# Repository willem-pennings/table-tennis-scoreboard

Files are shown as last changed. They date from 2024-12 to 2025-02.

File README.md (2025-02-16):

# Table tennis scoreboard
Hardware and software design for an electronic table tennis score board.

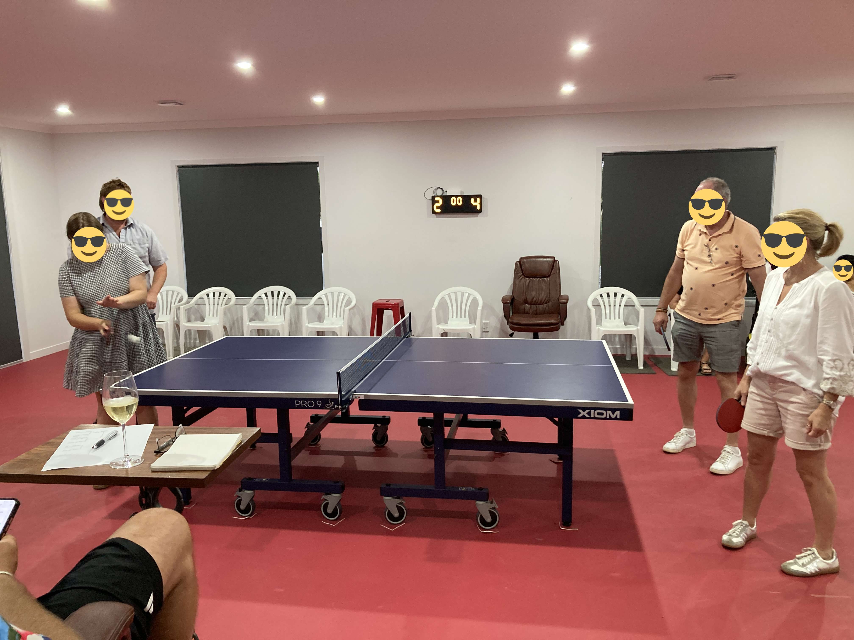
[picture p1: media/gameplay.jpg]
table tennis gameplay using the electronic scoreboard


## Features
This device has the following characteristics:
- Keeps track of scores, number of games, and timeouts.
- Remotely controlled using Wi-Fi and a web server.
- A mechanical design which is mainly based on laser-cut parts.
- WS2813 LEDs: adjustable screen colour and brightness.
- Software runs on an ESP32-S3.

## Building it
Mechanical parts are laser-cut from sheet material. An overview of individual parts:
- [Perspex Frost Midnight Black 9221, 3 mm thickness](https://www.laserbeest.nl/materialen/acrylaat-zwart-frost-3mm/)
  - ``front.svg``
  - ``back.svg``
  - ``wall-side-no-holes.svg``
  - ``wall-side-with-holes.svg``
  - ``wall-top-bottom.svg``
- [Perspex Frost Slate Grey 9T23, 3 mm thickness](https://www.laserbeest.nl/materialen/acrylaat-frost-donkergrijs-3-mm/)
  - ``diffuser-major.svg``
  - ``diffuser-minor.svg``
  - ``diffuser-timeout.svg``
- [PE rigid foam, 20 mm thickness](https://snijlab.nl/en/products/pe-rigid-foam?variant=48708138500423)
  - ``lightbox.svg``

Production files have also been prepared which can be sent to Dutch lasercutting companies as-is:
 - ``mechanical/production/production-laserbeest.pdf``
 - ``mechanical/production/production-snijlab.pdf``

The following additional parts are required to assemble the enclosure:
- 50x ISO7380 screw, M3x10.
- 15x M3x50 standoff, fully threaded, black ([example](https://www.aliexpress.com/item/1005004063804402.html)).
- 15x M3x20 standoff, fully threaded ([example](https://www.aliexpress.com/item/4000152799825.html)).
- USB type C extension cable ([example](https://www.aliexpress.com/item/1005005446667716.html)).
- Cyanoacrylate glue to join the frosted diffusers to the front plate.

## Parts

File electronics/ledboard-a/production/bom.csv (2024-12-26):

Designator | Footprint | Quantity | Value | LCSC Part #
C1, C10, C11, C12, C13, C14, C15, C16, C17, C18, C19, C2, C20, C21, C22, C23, C24, C25, C26, C27, C28, C29, C3, C30, C31, C32, C33, C34, C35, C36, C37, C38, C39, C4, C40, C41, C42, C43, C44, C45, C46, C47, C48, C49, C5, C50, C51, C52, C53, C54, C55, C56, C57, C58, C59, C6, C60, C61, C62, C63, C64, C65, C66, C67, C68, C69, C7, C70, C71, C72, C73, C74, C75, C8, C9 | 0603 | 75 | 100 nF | C14663
D1, D10, D11, D12, D13, D14, D15, D16, D17, D18, D19, D2, D20, D21, D22, D23, D24, D25, D26, D27, D28, D29, D3, D30, D31, D32, D33, D34, D35, D36, D37, D38, D39, D4, D40, D41, D42, D43, D44, D45, D46, D47, D48, D49, D5, D50, D51, D52, D53, D54, D55, D56, D57, D58, D59, D6, D60, D61, D62, D63, D64, D65, D66, D67, D68, D69, D7, D70, D71, D72, D73, D74, D75, D8, D9 | LED_WS2812_PLCC6_5.0x5.0mm_P1.6mm | 75 | WS2813 | C160214
H1, H2, H3, H4, H5 | MountingHole_3.2mm_M3_DIN965_Pad | 5 | MountingHole
J1 | Dorabo DB128V-5.08-2P | 1 | Conn_01x02
J2 | Dorabo DB128V-5.08-4P | 1 | Conn_01x04
KiKit_FID_B_1, KiKit_FID_B_2, KiKit_FID_B_3, KiKit_FID_B_4, KiKit_FID_T_1, KiKit_FID_T_2, KiKit_FID_T_3, KiKit_FID_T_4 | Fiducial | 8 | Fiducial
KiKit_MB_1_1, KiKit_MB_1_2, KiKit_MB_1_3, KiKit_MB_1_4, KiKit_MB_1_5, KiKit_MB_1_6, KiKit_MB_1_7, KiKit_MB_1_8, KiKit_MB_2_1, KiKit_MB_2_2, KiKit_MB_2_3, KiKit_MB_2_4, KiKit_MB_2_5, KiKit_MB_2_6, KiKit_MB_2_7, KiKit_MB_2_8, KiKit_MB_3_1, KiKit_MB_3_2, KiKit_MB_3_3, KiKit_MB_3_4, KiKit_MB_3_5, KiKit_MB_3_6, KiKit_MB_3_7, KiKit_MB_3_8, KiKit_MB_4_1, KiKit_MB_4_2, KiKit_MB_4_3, KiKit_MB_4_4, KiKit_MB_4_5, KiKit_MB_4_6, KiKit_MB_4_7, KiKit_MB_4_8, KiKit_MB_5_1, KiKit_MB_5_2, KiKit_MB_5_3, KiKit_MB_5_4, KiKit_MB_5_5, KiKit_MB_5_6, KiKit_MB_5_7, KiKit_MB_5_8, KiKit_MB_6_1, KiKit_MB_6_2, KiKit_MB_6_3, KiKit_MB_6_4, KiKit_MB_6_5, KiKit_MB_6_6, KiKit_MB_6_7, KiKit_MB_6_8, KiKit_MB_7_1, KiKit_MB_7_2, KiKit_MB_7_3, KiKit_MB_7_4, KiKit_MB_7_5, KiKit_MB_7_6, KiKit_MB_7_7, KiKit_MB_7_8, KiKit_MB_8_1, KiKit_MB_8_2, KiKit_MB_8_3, KiKit_MB_8_4, KiKit_MB_8_5, KiKit_MB_8_6, KiKit_MB_8_7, KiKit_MB_8_8, KiKit_TO_1, KiKit_TO_2, KiKit_TO_3 | NPTH | 67 | NPTH
TH1, TH2, TH3 | JLCPCB tooling hole | 3 | MountingHole

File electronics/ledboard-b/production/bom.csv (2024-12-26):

Designator | Footprint | Quantity | Value | LCSC Part #
C100, C101, C102, C103, C104, C105, C106, C107, C108, C109, C110, C111, C112, C113, C114, C115, C116, C117, C118, C119, C120, C121, C122, C123, C124, C125, C126, C127, C128, C129, C130, C131, C132, C133, C134, C135, C136, C137, C138, C139, C140, C141, C142, C143, C144, C145, C146, C147, C148, C149, C150, C76, C77, C78, C79, C80, C81, C82, C83, C84, C85, C86, C87, C88, C89, C90, C91, C92, C93, C94, C95, C96, C97, C98, C99 | 0603 | 75 | 100 nF | C14663
D100, D101, D102, D103, D104, D105, D106, D107, D108, D109, D110, D111, D112, D113, D114, D115, D116, D117, D118, D119, D120, D121, D122, D123, D124, D125, D126, D127, D128, D129, D130, D131, D132, D133, D134, D135, D136, D137, D138, D139, D140, D141, D142, D143, D144, D145, D146, D147, D148, D149, D150, D76, D77, D78, D79, D80, D81, D82, D83, D84, D85, D86, D87, D88, D89, D90, D91, D92, D93, D94, D95, D96, D97, D98, D99 | LED_WS2812_PLCC6_5.0x5.0mm_P1.6mm | 75 | WS2813 | C160214
H1, H2, H3, H4, H5 | MountingHole_3.2mm_M3_DIN965_Pad | 5 | MountingHole
J1 | Dorabo DB128V-5.08-4P | 1 | Conn_01x04
J2 | Dorabo DB128V-5.08-2P | 1 | Conn_01x02
KiKit_FID_B_1, KiKit_FID_B_2, KiKit_FID_B_3, KiKit_FID_B_4, KiKit_FID_T_1, KiKit_FID_T_2, KiKit_FID_T_3, KiKit_FID_T_4 | Fiducial | 8 | Fiducial
KiKit_MB_1_1, KiKit_MB_1_2, KiKit_MB_1_3, KiKit_MB_1_4, KiKit_MB_1_5, KiKit_MB_1_6, KiKit_MB_1_7, KiKit_MB_1_8, KiKit_MB_2_1, KiKit_MB_2_2, KiKit_MB_2_3, KiKit_MB_2_4, KiKit_MB_2_5, KiKit_MB_2_6, KiKit_MB_2_7, KiKit_MB_2_8, KiKit_MB_3_1, KiKit_MB_3_2, KiKit_MB_3_3, KiKit_MB_3_4, KiKit_MB_3_5, KiKit_MB_3_6, KiKit_MB_3_7, KiKit_MB_3_8, KiKit_MB_4_1, KiKit_MB_4_2, KiKit_MB_4_3, KiKit_MB_4_4, KiKit_MB_4_5, KiKit_MB_4_6, KiKit_MB_4_7, KiKit_MB_4_8, KiKit_MB_5_1, KiKit_MB_5_2, KiKit_MB_5_3, KiKit_MB_5_4, KiKit_MB_5_5, KiKit_MB_5_6, KiKit_MB_5_7, KiKit_MB_5_8, KiKit_MB_6_1, KiKit_MB_6_2, KiKit_MB_6_3, KiKit_MB_6_4, KiKit_MB_6_5, KiKit_MB_6_6, KiKit_MB_6_7, KiKit_MB_6_8, KiKit_MB_7_1, KiKit_MB_7_2, KiKit_MB_7_3, KiKit_MB_7_4, KiKit_MB_7_5, KiKit_MB_7_6, KiKit_MB_7_7, KiKit_MB_7_8, KiKit_MB_8_1, KiKit_MB_8_2, KiKit_MB_8_3, KiKit_MB_8_4, KiKit_MB_8_5, KiKit_MB_8_6, KiKit_MB_8_7, KiKit_MB_8_8, KiKit_TO_1, KiKit_TO_2, KiKit_TO_3 | NPTH | 67 | NPTH
TH1, TH2, TH3 | JLCPCB tooling hole | 3 | MountingHole

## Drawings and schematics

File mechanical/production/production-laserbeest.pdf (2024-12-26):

## PLAAT#: 03 PLAAT#: 02

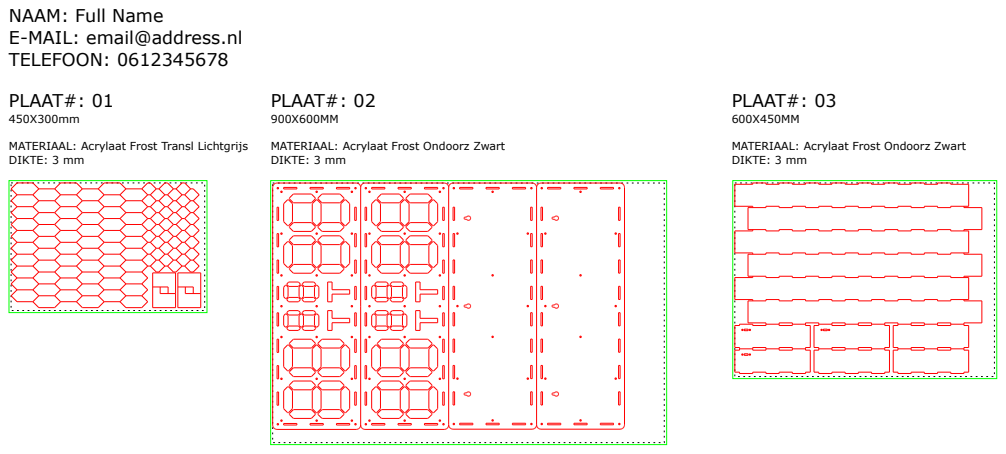
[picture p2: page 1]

NAAM: Full Name
E-MAIL: email@address.nl
TELEFOON: 0612345678
PLAAT#: 01

MATERIAAL: Acrylaat Frost Transl Lichtgrijs
DIKTE: 3 mm

MATERIAAL: Acrylaat Frost Ondoorz Zwart

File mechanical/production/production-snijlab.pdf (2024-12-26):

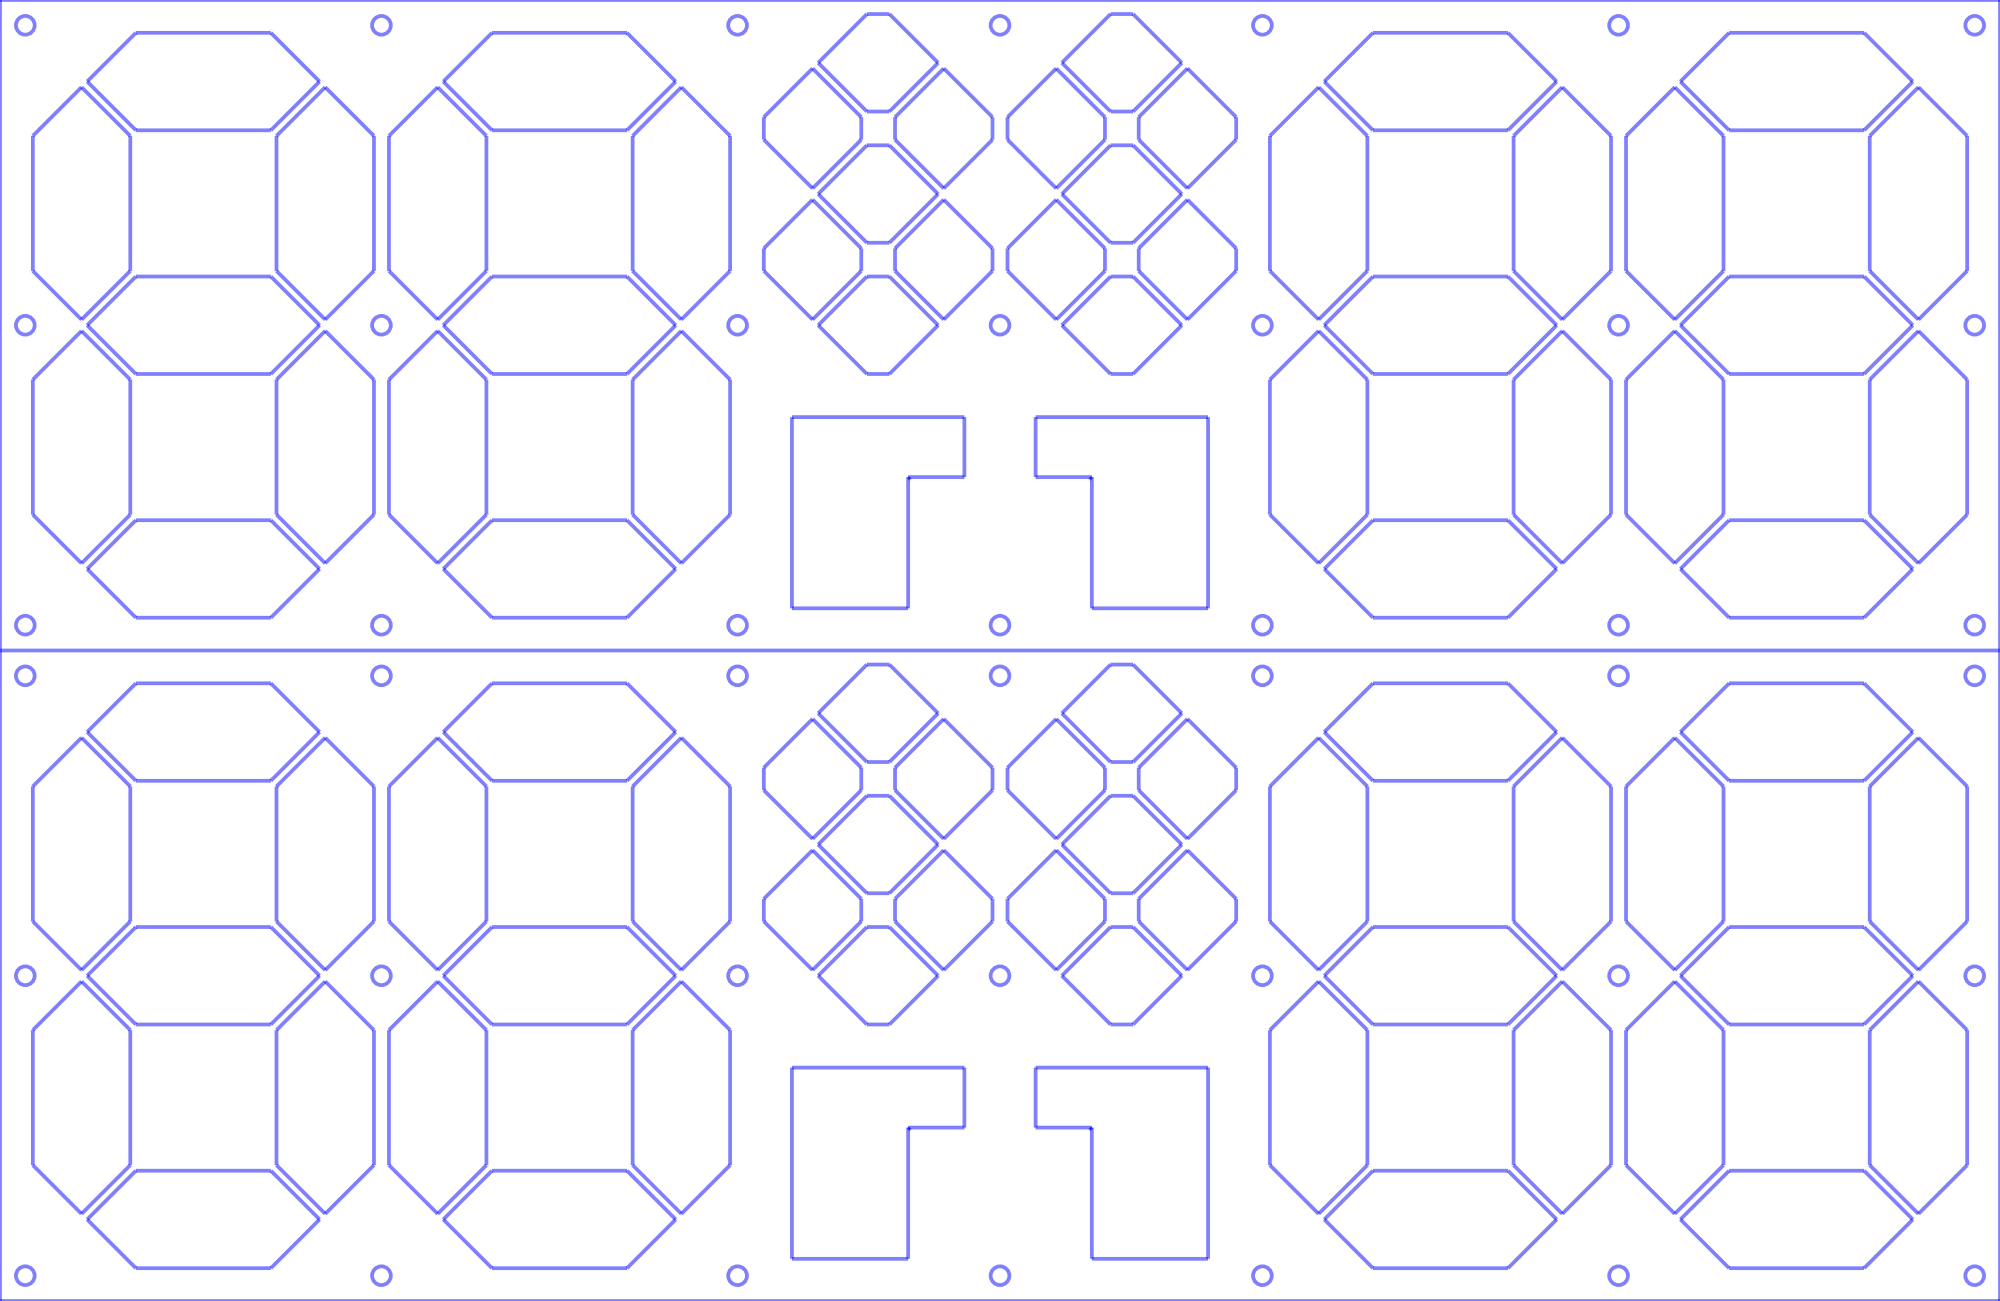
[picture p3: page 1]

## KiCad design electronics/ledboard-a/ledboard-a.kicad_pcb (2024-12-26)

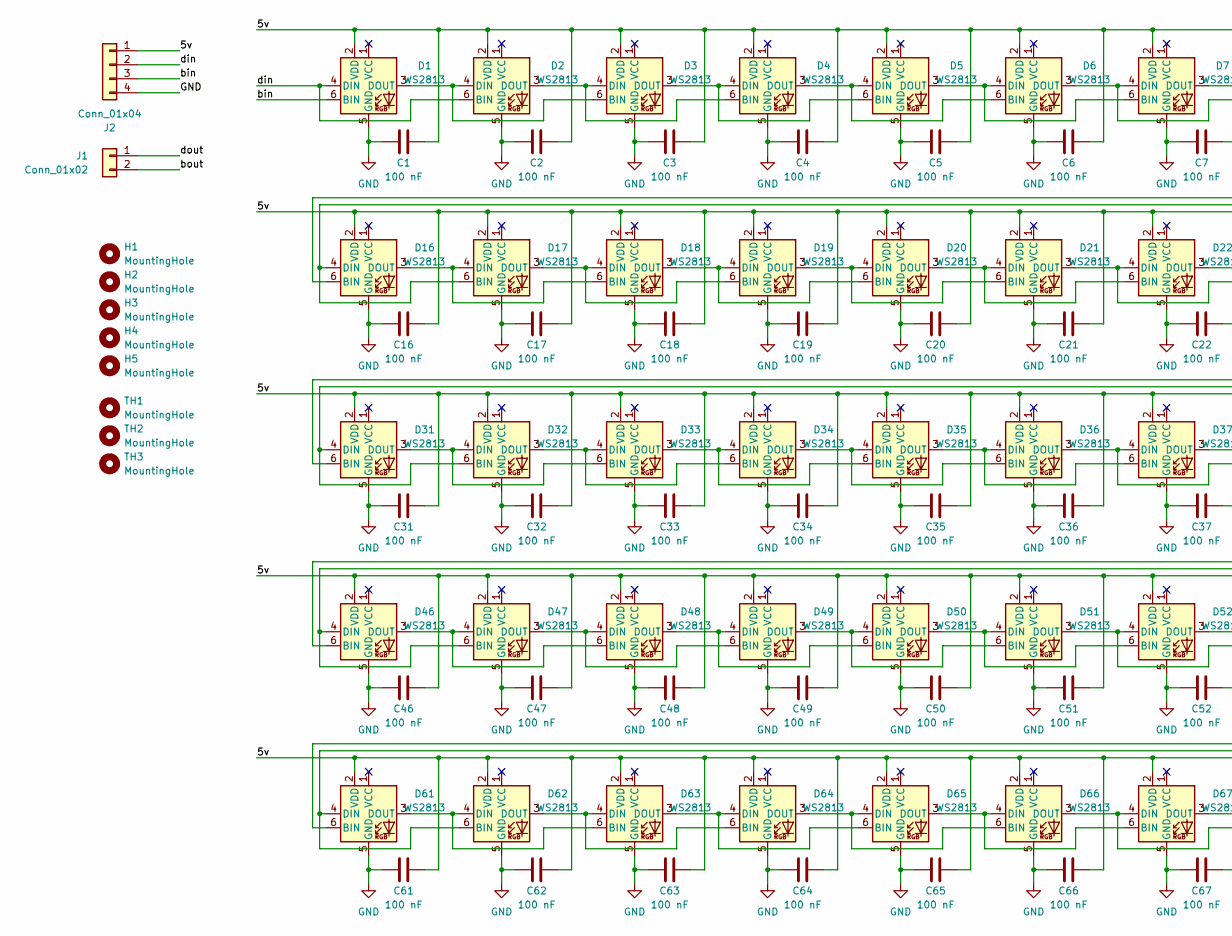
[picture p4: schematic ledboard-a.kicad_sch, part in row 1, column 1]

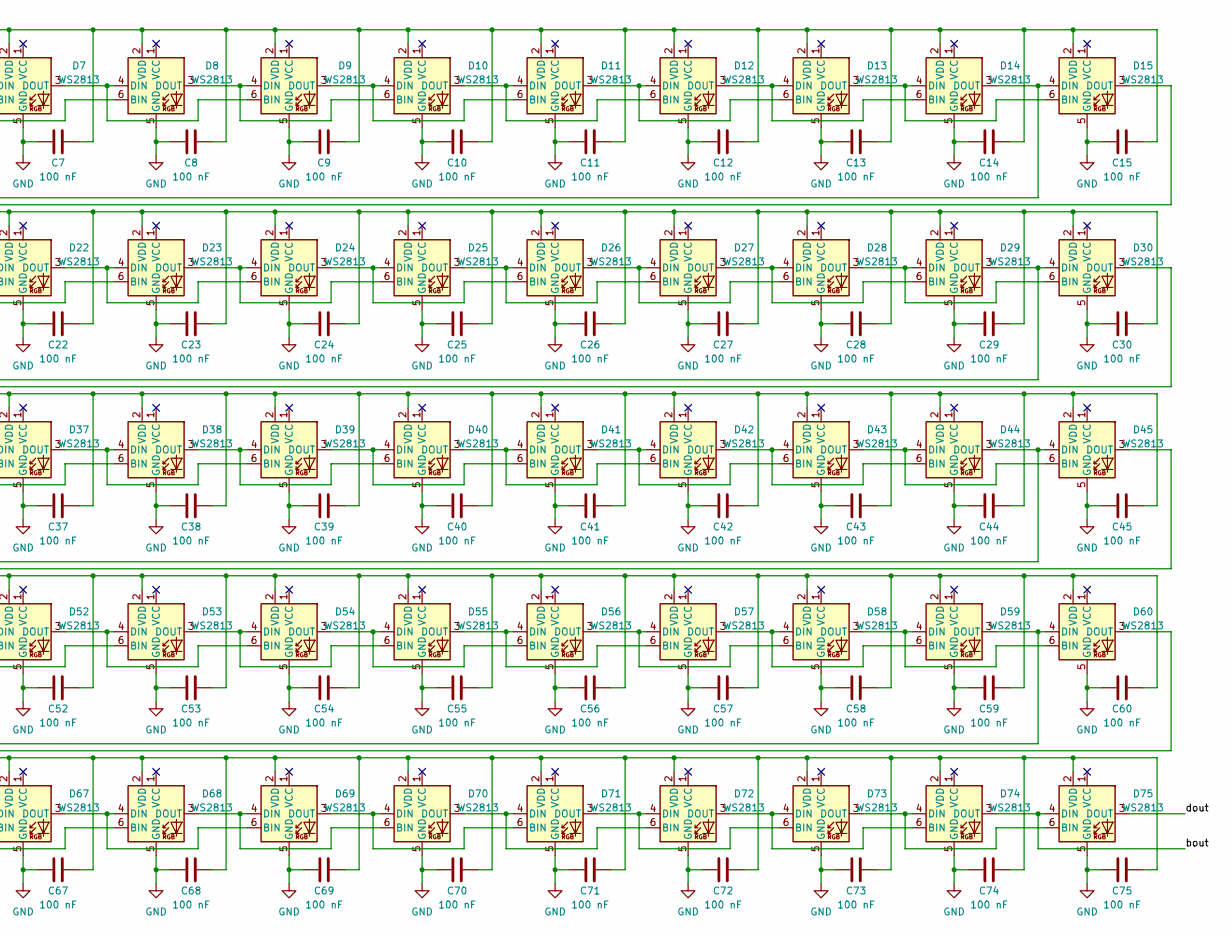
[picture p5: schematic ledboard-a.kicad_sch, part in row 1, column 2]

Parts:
C1, C2, C3, C4, C5, C6, C7, C8, C9, C10, C11, C12, C13, C14, C15, C16, C17, C18, C19, C20, C21, C22, C23, C24, C25, C26, C27, C28, C29, C30, C31, C32, C33, C34, C35, C36, C37, C38, C39, C40, C41, C42, C43, C44, C45, C46, C47, C48, C49, C50, C51, C52, C53, C54, C55, C56, C57, C58, C59, C60, C61, C62, C63, C64, C65, C66, C67, C68, C69, C70, C71, C72, C73, C74, C75: 100 nF; C_0603_1608Metric; LCSC C14663
D1, D2, D3, D4, D5, D6, D7, D8, D9, D10, D11, D12, D13, D14, D15, D16, D17, D18, D19, D20, D21, D22, D23, D24, D25, D26, D27, D28, D29, D30, D31, D32, D33, D34, D35, D36, D37, D38, D39, D40, D41, D42, D43, D44, D45, D46, D47, D48, D49, D50, D51, D52, D53, D54, D55, D56, D57, D58, D59, D60, D61, D62, D63, D64, D65, D66, D67, D68, D69, D70, D71, D72, D73, D74, D75: WS2813; LED_WS2812_PLCC6_5.0x5.0mm_P1.6mm; LCSC C160214
H1, H2, H3, H4, H5: MountingHole; MountingHole_3.2mm_M3_DIN965_Pad
J1: Conn_01x02; Dorabo DB128V-5.08-2P
J2: Conn_01x04; Dorabo DB128V-5.08-4P
TH1, TH2, TH3: MountingHole; JLCPCB tooling hole

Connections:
/5v: C1.2, C2.2, C3.2, C4.2, C5.2, C6.2, C7.2, C8.2, C9.2, C10.2, C11.2, C12.2, C13.2, C14.2, C15.2, C16.2, C17.2, C18.2, C19.2, C20.2, C21.2, C22.2, C23.2, C24.2, C25.2, C26.2, C27.2, C28.2, C29.2, C30.2, C31.2, C32.2, C33.2, C34.2, C35.2, C36.2, C37.2, C38.2, C39.2, C40.2, C41.2, C42.2, C43.2, C44.2, C45.2, C46.2, C47.2, C48.2, C49.2, C50.2, C51.2, C52.2, C53.2, C54.2, C55.2, C56.2, C57.2, C58.2, C59.2, C60.2, C61.2, C62.2, C63.2, C64.2, C65.2, C66.2, C67.2, C68.2, C69.2, C70.2, C71.2, C72.2, C73.2, C74.2, C75.2, D1.2 (VDD), D2.2 (VDD), D3.2 (VDD), D4.2 (VDD), D5.2 (VDD), D6.2 (VDD), D7.2 (VDD), D8.2 (VDD), D9.2 (VDD), D10.2 (VDD), D11.2 (VDD), D12.2 (VDD), D13.2 (VDD), D14.2 (VDD), D15.2 (VDD), D16.2 (VDD), D17.2 (VDD), D18.2 (VDD), D19.2 (VDD), D20.2 (VDD), D21.2 (VDD), D22.2 (VDD), D23.2 (VDD), D24.2 (VDD), D25.2 (VDD), D26.2 (VDD), D27.2 (VDD), D28.2 (VDD), D29.2 (VDD), D30.2 (VDD), D31.2 (VDD), D32.2 (VDD), D33.2 (VDD), D34.2 (VDD), D35.2 (VDD), D36.2 (VDD), D37.2 (VDD), D38.2 (VDD), D39.2 (VDD), D40.2 (VDD), D41.2 (VDD), D42.2 (VDD), D43.2 (VDD), D44.2 (VDD), D45.2 (VDD), D46.2 (VDD), D47.2 (VDD), D48.2 (VDD), D49.2 (VDD), D50.2 (VDD), D51.2 (VDD), D52.2 (VDD), D53.2 (VDD), D54.2 (VDD), D55.2 (VDD), D56.2 (VDD), D57.2 (VDD), D58.2 (VDD), D59.2 (VDD), D60.2 (VDD), D61.2 (VDD), D62.2 (VDD), D63.2 (VDD), D64.2 (VDD), D65.2 (VDD), D66.2 (VDD), D67.2 (VDD), D68.2 (VDD), D69.2 (VDD), D70.2 (VDD), D71.2 (VDD), D72.2 (VDD), D73.2 (VDD), D74.2 (VDD), D75.2 (VDD), J2.1
/bin: D1.6 (BIN), J2.3
/bout: D74.3 (DOUT), D75.4 (DIN), J1.2
/din: D1.4 (DIN), D2.6 (BIN), J2.2
/dout: D75.3 (DOUT), J1.1
GND: C1.1, C2.1, C3.1, C4.1, C5.1, C6.1, C7.1, C8.1, C9.1, C10.1, C11.1, C12.1, C13.1, C14.1, C15.1, C16.1, C17.1, C18.1, C19.1, C20.1, C21.1, C22.1, C23.1, C24.1, C25.1, C26.1, C27.1, C28.1, C29.1, C30.1, C31.1, C32.1, C33.1, C34.1, C35.1, C36.1, C37.1, C38.1, C39.1, C40.1, C41.1, C42.1, C43.1, C44.1, C45.1, C46.1, C47.1, C48.1, C49.1, C50.1, C51.1, C52.1, C53.1, C54.1, C55.1, C56.1, C57.1, C58.1, C59.1, C60.1, C61.1, C62.1, C63.1, C64.1, C65.1, C66.1, C67.1, C68.1, C69.1, C70.1, C71.1, C72.1, C73.1, C74.1, C75.1, D1.5 (GND), D2.5 (GND), D3.5 (GND), D4.5 (GND), D5.5 (GND), D6.5 (GND), D7.5 (GND), D8.5 (GND), D9.5 (GND), D10.5 (GND), D11.5 (GND), D12.5 (GND), D13.5 (GND), D14.5 (GND), D15.5 (GND), D16.5 (GND), D17.5 (GND), D18.5 (GND), D19.5 (GND), D20.5 (GND), D21.5 (GND), D22.5 (GND), D23.5 (GND), D24.5 (GND), D25.5 (GND), D26.5 (GND), D27.5 (GND), D28.5 (GND), D29.5 (GND), D30.5 (GND), D31.5 (GND), D32.5 (GND), D33.5 (GND), D34.5 (GND), D35.5 (GND), D36.5 (GND), D37.5 (GND), D38.5 (GND), D39.5 (GND), D40.5 (GND), D41.5 (GND), D42.5 (GND), D43.5 (GND), D44.5 (GND), D45.5 (GND), D46.5 (GND), D47.5 (GND), D48.5 (GND), D49.5 (GND), D50.5 (GND), D51.5 (GND), D52.5 (GND), D53.5 (GND), D54.5 (GND), D55.5 (GND), D56.5 (GND), D57.5 (GND), D58.5 (GND), D59.5 (GND), D60.5 (GND), D61.5 (GND), D62.5 (GND), D63.5 (GND), D64.5 (GND), D65.5 (GND), D66.5 (GND), D67.5 (GND), D68.5 (GND), D69.5 (GND), D70.5 (GND), D71.5 (GND), D72.5 (GND), D73.5 (GND), D74.5 (GND), D75.5 (GND), J2.4
unnamed: D1.3 (DOUT), D2.4 (DIN), D3.6 (BIN)
unnamed: D2.3 (DOUT), D3.4 (DIN), D4.6 (BIN)
unnamed: D3.3 (DOUT), D4.4 (DIN), D5.6 (BIN)
unnamed: D4.3 (DOUT), D5.4 (DIN), D6.6 (BIN)
unnamed: D5.3 (DOUT), D6.4 (DIN), D7.6 (BIN)
unnamed: D6.3 (DOUT), D7.4 (DIN), D8.6 (BIN)
unnamed: D7.3 (DOUT), D8.4 (DIN), D9.6 (BIN)
unnamed: D8.3 (DOUT), D9.4 (DIN), D10.6 (BIN)
unnamed: D9.3 (DOUT), D10.4 (DIN), D11.6 (BIN)
unnamed: D10.3 (DOUT), D11.4 (DIN), D12.6 (BIN)
unnamed: D11.3 (DOUT), D12.4 (DIN), D13.6 (BIN)
unnamed: D12.3 (DOUT), D13.4 (DIN), D14.6 (BIN)
unnamed: D13.3 (DOUT), D14.4 (DIN), D15.6 (BIN)
unnamed: D14.3 (DOUT), D15.4 (DIN), D16.6 (BIN)
unnamed: D15.3 (DOUT), D16.4 (DIN), D17.6 (BIN)
unnamed: D16.3 (DOUT), D17.4 (DIN), D18.6 (BIN)
unnamed: D17.3 (DOUT), D18.4 (DIN), D19.6 (BIN)
unnamed: D18.3 (DOUT), D19.4 (DIN), D20.6 (BIN)
unnamed: D19.3 (DOUT), D20.4 (DIN), D21.6 (BIN)
unnamed: D20.3 (DOUT), D21.4 (DIN), D22.6 (BIN)
unnamed: D21.3 (DOUT), D22.4 (DIN), D23.6 (BIN)
unnamed: D22.3 (DOUT), D23.4 (DIN), D24.6 (BIN)
unnamed: D23.3 (DOUT), D24.4 (DIN), D25.6 (BIN)
unnamed: D24.3 (DOUT), D25.4 (DIN), D26.6 (BIN)
unnamed: D25.3 (DOUT), D26.4 (DIN), D27.6 (BIN)
unnamed: D26.3 (DOUT), D27.4 (DIN), D28.6 (BIN)
unnamed: D27.3 (DOUT), D28.4 (DIN), D29.6 (BIN)
unnamed: D28.3 (DOUT), D29.4 (DIN), D30.6 (BIN)
unnamed: D29.3 (DOUT), D30.4 (DIN), D31.6 (BIN)
unnamed: D30.3 (DOUT), D31.4 (DIN), D32.6 (BIN)
unnamed: D31.3 (DOUT), D32.4 (DIN), D33.6 (BIN)
unnamed: D32.3 (DOUT), D33.4 (DIN), D34.6 (BIN)
unnamed: D33.3 (DOUT), D34.4 (DIN), D35.6 (BIN)
unnamed: D34.3 (DOUT), D35.4 (DIN), D36.6 (BIN)
unnamed: D35.3 (DOUT), D36.4 (DIN), D37.6 (BIN)
unnamed: D36.3 (DOUT), D37.4 (DIN), D38.6 (BIN)
unnamed: D37.3 (DOUT), D38.4 (DIN), D39.6 (BIN)
unnamed: D38.3 (DOUT), D39.4 (DIN), D40.6 (BIN)
unnamed: D39.3 (DOUT), D40.4 (DIN), D41.6 (BIN)
unnamed: D40.3 (DOUT), D41.4 (DIN), D42.6 (BIN)
unnamed: D41.3 (DOUT), D42.4 (DIN), D43.6 (BIN)
unnamed: D42.3 (DOUT), D43.4 (DIN), D44.6 (BIN)
unnamed: D43.3 (DOUT), D44.4 (DIN), D45.6 (BIN)
unnamed: D44.3 (DOUT), D45.4 (DIN), D46.6 (BIN)
unnamed: D45.3 (DOUT), D46.4 (DIN), D47.6 (BIN)
unnamed: D46.3 (DOUT), D47.4 (DIN), D48.6 (BIN)
unnamed: D47.3 (DOUT), D48.4 (DIN), D49.6 (BIN)
unnamed: D48.3 (DOUT), D49.4 (DIN), D50.6 (BIN)
unnamed: D49.3 (DOUT), D50.4 (DIN), D51.6 (BIN)
unnamed: D50.3 (DOUT), D51.4 (DIN), D52.6 (BIN)
unnamed: D51.3 (DOUT), D52.4 (DIN), D53.6 (BIN)
unnamed: D52.3 (DOUT), D53.4 (DIN), D54.6 (BIN)
unnamed: D53.3 (DOUT), D54.4 (DIN), D55.6 (BIN)
unnamed: D54.3 (DOUT), D55.4 (DIN), D56.6 (BIN)
unnamed: D55.3 (DOUT), D56.4 (DIN), D57.6 (BIN)
unnamed: D56.3 (DOUT), D57.4 (DIN), D58.6 (BIN)
unnamed: D57.3 (DOUT), D58.4 (DIN), D59.6 (BIN)
unnamed: D58.3 (DOUT), D59.4 (DIN), D60.6 (BIN)
unnamed: D59.3 (DOUT), D60.4 (DIN), D61.6 (BIN)
unnamed: D60.3 (DOUT), D61.4 (DIN), D62.6 (BIN)
unnamed: D61.3 (DOUT), D62.4 (DIN), D63.6 (BIN)
unnamed: D62.3 (DOUT), D63.4 (DIN), D64.6 (BIN)
unnamed: D63.3 (DOUT), D64.4 (DIN), D65.6 (BIN)
unnamed: D64.3 (DOUT), D65.4 (DIN), D66.6 (BIN)
unnamed: D65.3 (DOUT), D66.4 (DIN), D67.6 (BIN)
unnamed: D66.3 (DOUT), D67.4 (DIN), D68.6 (BIN)
unnamed: D67.3 (DOUT), D68.4 (DIN), D69.6 (BIN)
unnamed: D68.3 (DOUT), D69.4 (DIN), D70.6 (BIN)
unnamed: D69.3 (DOUT), D70.4 (DIN), D71.6 (BIN)
unnamed: D70.3 (DOUT), D71.4 (DIN), D72.6 (BIN)
unnamed: D71.3 (DOUT), D72.4 (DIN), D73.6 (BIN)
unnamed: D72.3 (DOUT), D73.4 (DIN), D74.6 (BIN)
unnamed: D73.3 (DOUT), D74.4 (DIN), D75.6 (BIN)

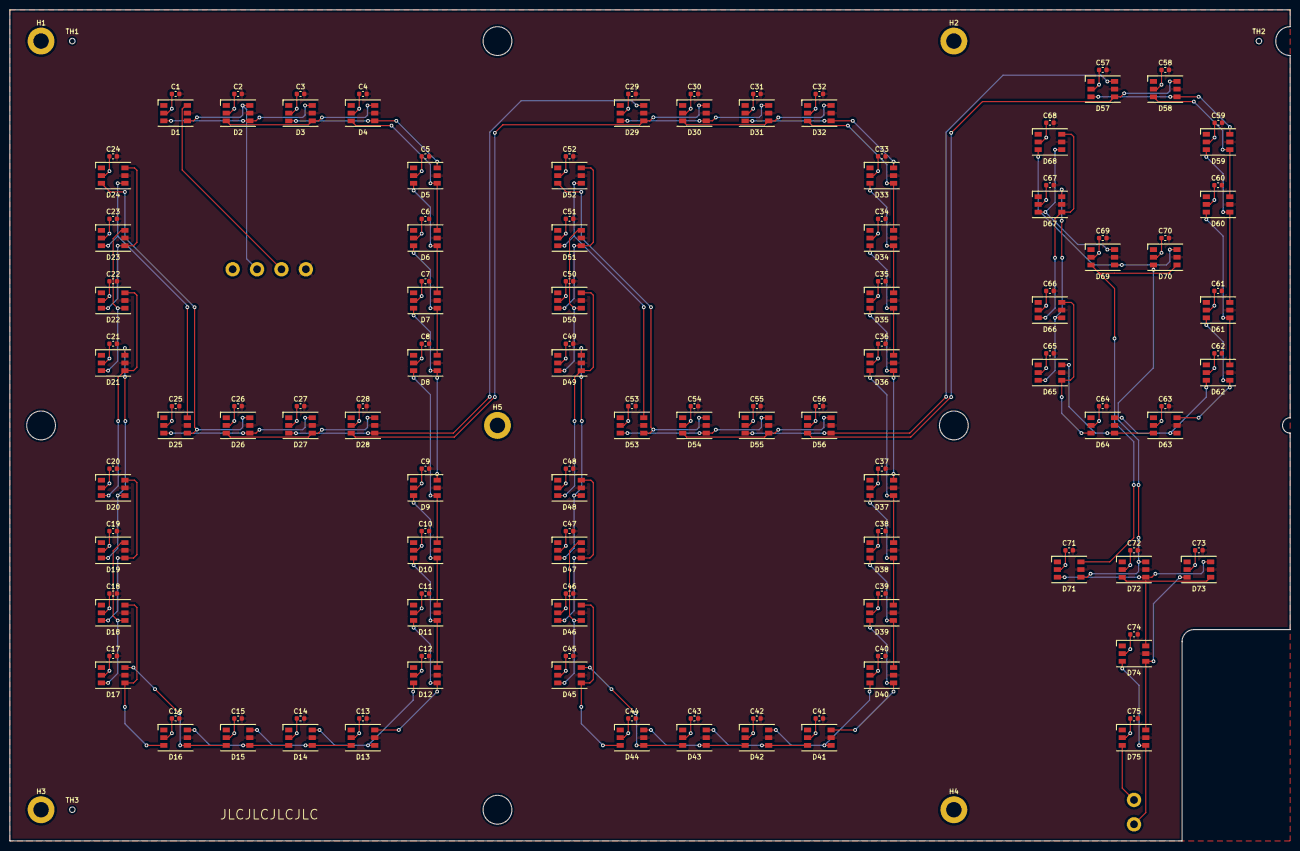
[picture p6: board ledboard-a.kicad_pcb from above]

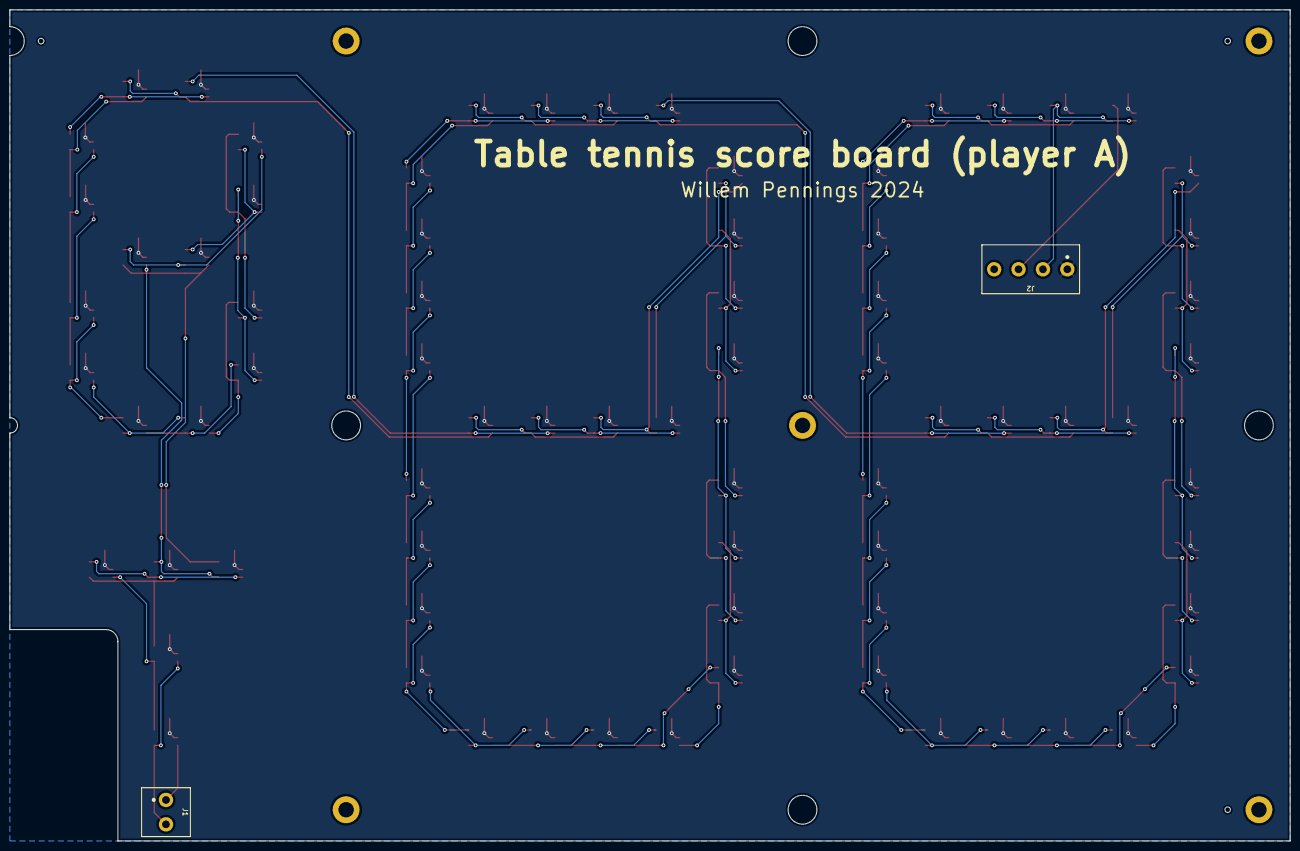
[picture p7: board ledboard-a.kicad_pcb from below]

Board: 2 copper layers, 266.5 x 173.0 mm, 160 parts (2 on the bottom side), 79 nets.

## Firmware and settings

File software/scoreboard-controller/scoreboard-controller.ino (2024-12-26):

/**
  Table tennis score board controller
  Copyright (c) by Willem Pennings, 2024
  For more information, visit https://willempennings.nl
**/

#include <FastLED.h>

// Controller library.
#include "src/scoreboard-controller.h"

// Create LED array.
CRGB leds[NUM_LEDS];

// Create the 7-segment displays to display the number of points and games for each player.
SevenSegmentDisplay player_1_tens(leds, START_P1_TENS, LEDS_PER_SEGMENT_SCORE);
SevenSegmentDisplay player_1_ones(leds, START_P1_ONES, LEDS_PER_SEGMENT_SCORE);
SevenSegmentDisplay player_1_games(leds, START_P1_GAMES, LEDS_PER_SEGMENT_GAME);
SevenSegmentDisplay player_2_tens(leds, START_P2_TENS, LEDS_PER_SEGMENT_SCORE);
SevenSegmentDisplay player_2_ones(leds, START_P2_ONES, LEDS_PER_SEGMENT_SCORE);
SevenSegmentDisplay player_2_games(leds, START_P2_GAMES, LEDS_PER_SEGMENT_GAME);

// Create the timeout indicators for each player.
TimeoutIndicator player_1_timeout(leds, START_P1_TIMEOUT);
TimeoutIndicator player_2_timeout(leds, START_P2_TIMEOUT);

// Create the score and game counters to keep track of the number of points and games for each player.
ScoreCounter score_counter_1(&player_1_tens, &player_1_ones, ScoreCounter::LEFT);
ScoreCounter score_counter_2(&player_2_tens, &player_2_ones, ScoreCounter::RIGHT);
GameCounter game_counter_1(&player_1_games);
GameCounter game_counter_2(&player_2_games);

// Create the umpire to manage the game.
Umpire umpire(&score_counter_1, &score_counter_2, &game_counter_1, &game_counter_2,
  &player_1_timeout, &player_2_timeout);

// Create the web server which the user uses to interact with the umpire.
ScoreboardServer server_manager(WIFI_SSID, WIFI_PASSWORD, &umpire);

void setup() {
  // Wait a little.
  delay(1000);

  // Initialize the LED strip.
  FastLED.addLeds<WS2812, PIN_DATA, GRB>(leds, NUM_LEDS).setCorrection(TypicalLEDStrip);
  FastLED.setBrightness(0);

  // Start web server.
  server_manager.Begin();

  // Reset the match to begin.
  umpire.ResetMatch();
  FastLED.show();

  // Gradually ramp up the brightness to the set value.
  for (int i = 0; i < BRIGHTNESS; i++) {
    FastLED.setBrightness(i);
    FastLED.show();
    delay(10);
  }
}

void loop() {
  // Web server requests are handled in the background.
}

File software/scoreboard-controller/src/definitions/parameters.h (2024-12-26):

#ifndef parameters_h
#define parameters_h

// Game rules (in case of GAMES_TO_WIN_MATCH, this is only the default value).
const uint8_t WIN_SCORE = 11;
const uint8_t WIN_DIFFERENCE = 2;
const uint8_t GAMES_TO_WIN_MATCH = 3;

// Appearance.
const CRGB DEFAULT_COLOR = CRGB::White;
const CRGB WIN_EFFECT_COLOR = CRGB::Green;

// LED matrix.
const uint8_t NUM_LEDS = 150;
const uint8_t BRIGHTNESS = 128; // Do not go above 128 because the power supply can not handle that.

// LED string layout.
const uint8_t LEDS_PER_SEGMENT_SCORE = 4;
const uint8_t LEDS_PER_SEGMENT_GAME = 2;
const uint8_t LEDS_PER_TIMEOUT_INDICATOR = 5;
const uint8_t START_P1_TENS = 0;
const uint8_t START_P1_ONES = 28;
const uint8_t START_P1_GAMES = 56;
const uint8_t START_P2_TENS = 94;
const uint8_t START_P2_ONES = 122;
const uint8_t START_P2_GAMES = 80;
const uint8_t START_P1_TIMEOUT = 70;
const uint8_t START_P2_TIMEOUT = 75;

#endif
